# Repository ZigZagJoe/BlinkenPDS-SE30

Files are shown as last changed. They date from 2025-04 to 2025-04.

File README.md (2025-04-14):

68030 PDS Interposer / "BlinkenPDS" diagnostic board for SE/30/IIsi.

Top connector is a passthrough for card under test, side connector is for logic analyzer pins or a second card.
NOT intended for use in a case, though it will fit (poorly). 

BlinkenPDS (c) by zigzagjoe 2024

BlinkenPDS is licensed under a
Creative Commons Attribution-NonCommercial 4.0 International License.

You should have received a copy of the license along with this
work. If not, see <https://creativecommons.org/licenses/by-nc/4.0/>.

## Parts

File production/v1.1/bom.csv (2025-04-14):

Designator | Footprint | Quantity | Value | LCSC Part #
C1, C10, C11, C12, C13, C14, C15, C16, C17, C2, C23, C3, C4, C5, C6, C7, C8, C9 | 0805 | 18 | 10uF | C15850
C18, C19, C20, C21, C22 | CP_EIA-3528-15_AVX-H | 5 | 100uf | C16133
CN1 | 650949-5 RA MALE | 1 | PDS_LB_MALE
CN2 | 650874-4 RA FEMALE | 1 | PDS_PT_FEMALE RA
CN3 | 535098-5 ST FEMALE | 1 | PDS_PT_FEMALE ST
D1, D10, D11, D12, D13, D14, D15, D16, D17, D18, D19, D2, D20, D21, D22, D23, D24, D25, D26, D27, D28, D29, D3, D30, D31, D32, D4, D5, D6, D7, D8, D9 | 0603 | 32 | A | C2986059
D100, D101, D102, D65, D66, D68, D69, D70, D71, D72, D73, D74, D75, D76, D77, D78, D79, D80, D81, D82, D83, D84, D85, D86, D87, D88, D89, D90, D91, D92, D93, D94, D95, D96, D97, D98, D99 | 0603 | 37 | C | C72038
D103, D104, D105, D106 | 0603 | 4 | P | C2986058
D33, D34, D35, D36, D37, D38, D39, D40, D41, D42, D43, D44, D45, D46, D47, D48, D49, D50, D51, D52, D53, D54, D55, D56, D57, D58, D59, D60, D61, D62, D63, D64 | 0603 | 32 | D | C2286
R1, R10, R11, R12, R13, R14, R15, R16, R17, R18, R19, R2, R20, R21, R22, R23, R24, R25, R26, R27, R28, R29, R3, R30, R31, R32, R4, R5, R6, R7, R8, R9 | 0402 | 32 | 3.3K | C25890
R100, R101, R102, R33, R66, R67, R69, R70, R71, R72, R73, R74, R75, R76, R77, R78, R79, R80, R81, R82, R83, R84, R85, R86, R87, R88, R89, R90, R91, R92, R93, R94, R95, R96, R97, R98, R99 | 0402 | 37 | 510 | C25123
R103, R104 | 0402 | 2 | 680 | C25130
R105, R106 | 0402 | 2 | 2.4K | C25882
R34, R35, R36, R37, R38, R39, R40, R41, R42, R43, R44, R45, R46, R47, R48, R49, R50, R51, R52, R53, R54, R55, R56, R57, R58, R59, R60, R61, R62, R63, R64, R65 | 0402 | 32 | 1K | C25104
U1, U10, U11, U12, U13, U14, U15, U16, U17, U2, U3, U4, U5, U6, U7, U8, U9 | SOIC-14_3.9x8.7mm_P1.27mm | 17 | 74HC14D | C5605

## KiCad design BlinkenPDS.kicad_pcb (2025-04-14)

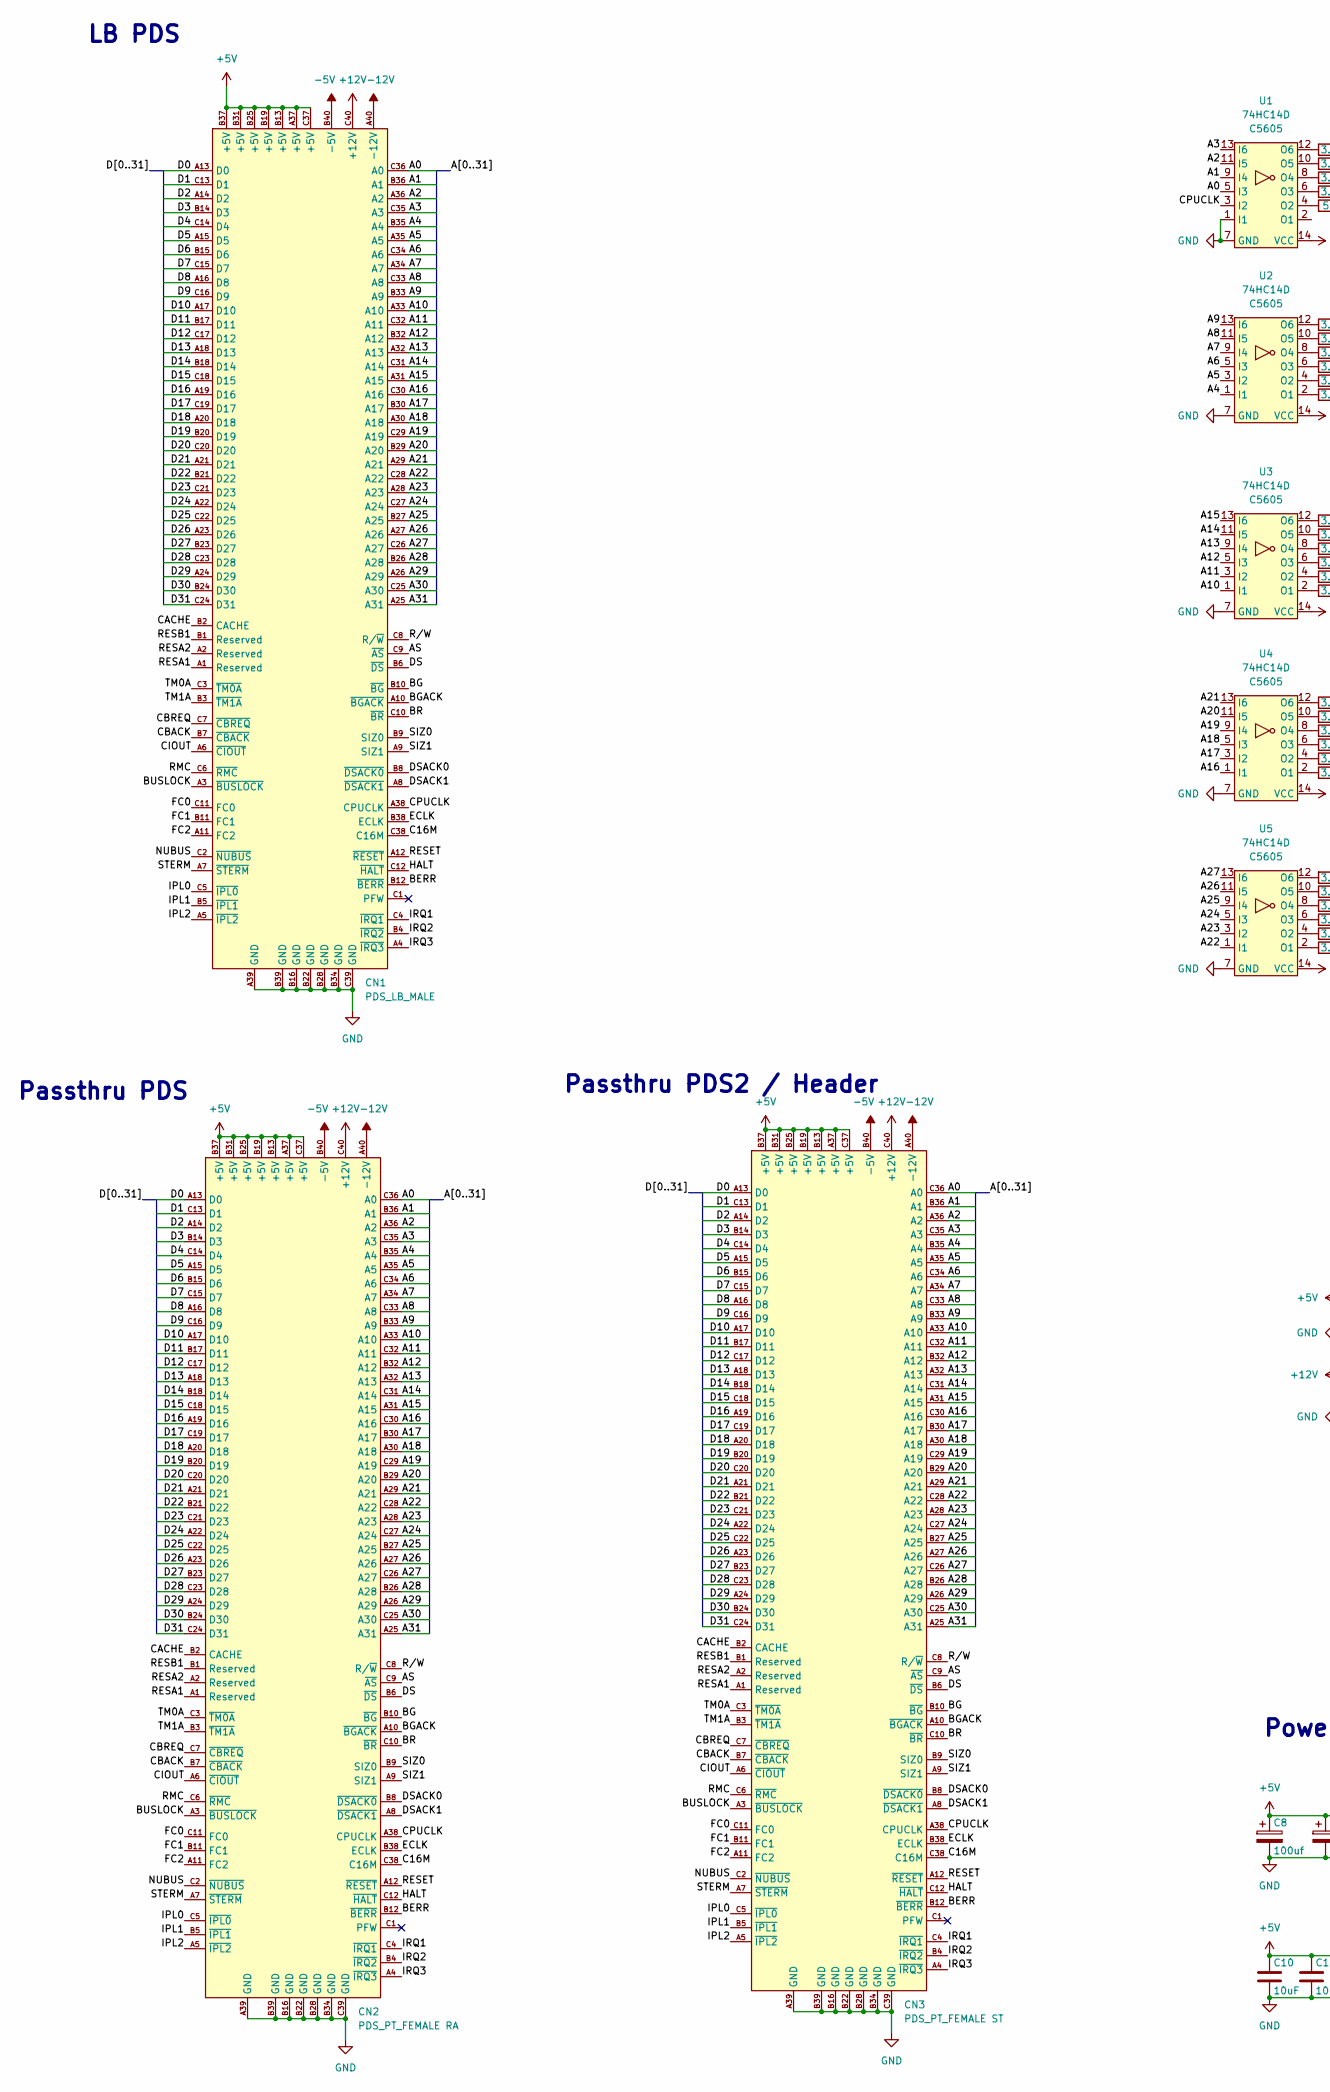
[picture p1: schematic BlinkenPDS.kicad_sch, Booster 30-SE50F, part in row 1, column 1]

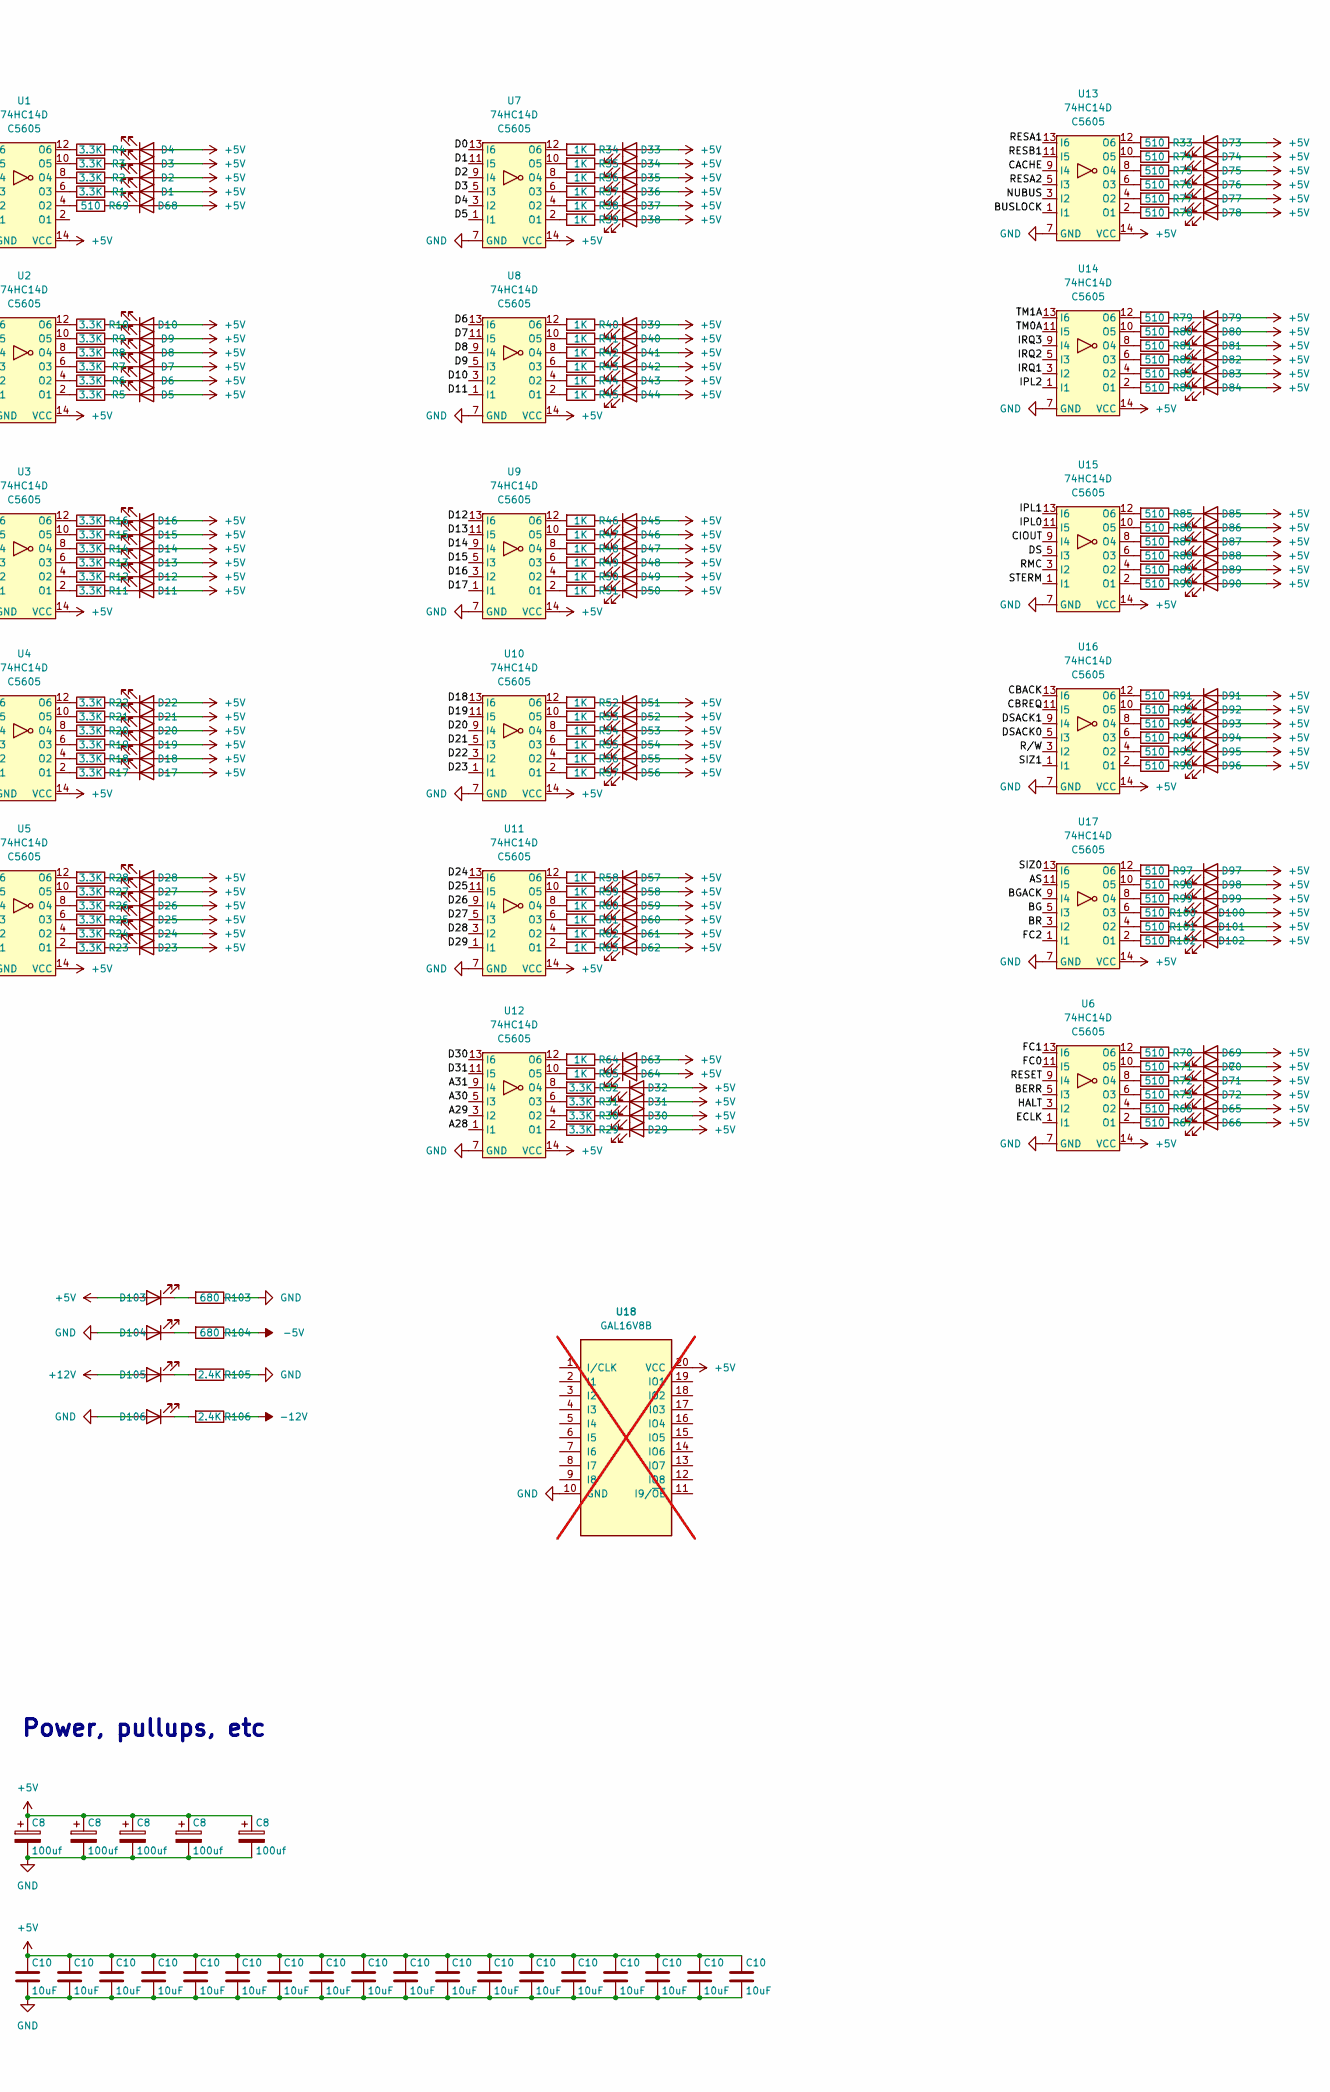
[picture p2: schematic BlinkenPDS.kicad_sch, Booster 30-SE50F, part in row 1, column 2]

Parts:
C8: 100uf; CP_EIA-3528-15_AVX-H; LCSC C16133
C10: 10uF; C_0805_2012Metric; PartNumber CL21A106KPFNNNG; LCSC C15850
CN1: PDS_LB_MALE; 650949-5 RA MALE
CN2: PDS_PT_FEMALE RA; 650874-4 RA FEMALE
CN3: PDS_PT_FEMALE ST; 535098-5 ST FEMALE
D1, D2, D3, D4, D5, D6, D7, D8, D9, D10, D11, D12, D13, D14, D15, D16, D17, D18, D19, D20, D21, D22, D23, D24, D25, D26, D27, D28, D29, D30, D31, D32: A; LED_0603_1608Metric_Label; PartNumber GRN; LCSC C2986059
D33, D34, D35, D36, D37, D38, D39, D40, D41, D42, D43, D44, D45, D46, D47, D48, D49, D50, D51, D52, D53, D54, D55, D56, D57, D58, D59, D60, D61, D62, D63, D64: D; LED_0603_1608Metric_Label; PartNumber Red; LCSC C2286
D65, D66, D68, D69, D70, D71, D72, D73, D74, D75, D76, D77, D78, D79, D80, D81, D82, D83, D84, D85, D86, D87, D88, D89, D90, D91, D92, D93, D94, D95, D96, D97, D98, D99, D100, D101, D102: C; LED_0603_1608Metric_Label; PartNumber YLW; LCSC C72038
D103, D104, D105, D106: P; LED_0603_1608Metric_Label; PartNumber Blue; LCSC C2986058
R1, R2, R3, R4, R5, R6, R7, R8, R9, R10, R11, R12, R13, R14, R15, R16, R17, R18, R19, R20, R21, R22, R23, R24, R25, R26, R27, R28, R29, R30, R31, R32: 3.3K; R_0402_1005Metric_NoLabel; LCSC C25890
R33, R66, R67, R69, R70, R71, R72, R73, R74, R75, R76, R77, R78, R79, R80, R81, R82, R83, R84, R85, R86, R87, R88, R89, R90, R91, R92, R93, R94, R95, R96, R97, R98, R99, R100, R101, R102: 510; R_0402_1005Metric_NoLabel; LCSC C25123
R34, R35, R36, R37, R38, R39, R40, R41, R42, R43, R44, R45, R46, R47, R48, R49, R50, R51, R52, R53, R54, R55, R56, R57, R58, R59, R60, R61, R62, R63, R64, R65: 1K; R_0402_1005Metric_NoLabel; LCSC C25104
R103, R104: 680; R_0402_1005Metric_NoLabel; LCSC C25130
R105, R106: 2.4K; R_0402_1005Metric_NoLabel; LCSC C25882
U1, U2, U3, U4, U5, U6, U7, U8, U9, U10, U11, U12, U13, U14, U15, U16, U17: 74HC14D; SOIC-14_3.9x8.7mm_P1.27mm; LCSC C5605
U18: GAL16V8B; DIP-20_W7.62mm_Socket_LongPads; not fitted

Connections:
+5V: C8.1, C10.1, CN1.A37 (+5V), CN1.B13 (+5V), CN1.B19 (+5V), CN1.B25 (+5V), CN1.B31 (+5V), CN1.B37 (+5V), CN1.C37 (+5V), CN2.A37 (+5V), CN2.B13 (+5V), CN2.B19 (+5V), CN2.B25 (+5V), CN2.B31 (+5V), CN2.B37 (+5V), CN2.C37 (+5V), CN3.A37 (+5V), CN3.B13 (+5V), CN3.B19 (+5V), CN3.B25 (+5V), CN3.B31 (+5V), CN3.B37 (+5V), CN3.C37 (+5V), D1.2 (A), D2.2 (A), D3.2 (A), D4.2 (A), D5.2 (A), D6.2 (A), D7.2 (A), D8.2 (A), D9.2 (A), D10.2 (A), D11.2 (A), D12.2 (A), D13.2 (A), D14.2 (A), D15.2 (A), D16.2 (A), D17.2 (A), D18.2 (A), D19.2 (A), D20.2 (A), D21.2 (A), D22.2 (A), D23.2 (A), D24.2 (A), D25.2 (A), D26.2 (A), D27.2 (A), D28.2 (A), D29.2 (A), D30.2 (A), D31.2 (A), D32.2 (A), D33.2 (A), D34.2 (A), D35.2 (A), D36.2 (A), D37.2 (A), D38.2 (A), D39.2 (A), D40.2 (A), D41.2 (A), D42.2 (A), D43.2 (A), D44.2 (A), D45.2 (A), D46.2 (A), D47.2 (A), D48.2 (A), D49.2 (A), D50.2 (A), D51.2 (A), D52.2 (A), D53.2 (A), D54.2 (A), D55.2 (A), D56.2 (A), D57.2 (A), D58.2 (A), D59.2 (A), D60.2 (A), D61.2 (A), D62.2 (A), D63.2 (A), D64.2 (A), D65.2 (A), D66.2 (A), D68.2 (A), D69.2 (A), D70.2 (A), D71.2 (A), D72.2 (A), D73.2 (A), D74.2 (A), D75.2 (A), D76.2 (A), D77.2 (A), D78.2 (A), D79.2 (A), D80.2 (A), D81.2 (A), D82.2 (A), D83.2 (A), D84.2 (A), D85.2 (A), D86.2 (A), D87.2 (A), D88.2 (A), D89.2 (A), D90.2 (A), D91.2 (A), D92.2 (A), D93.2 (A), D94.2 (A), D95.2 (A), D96.2 (A), D97.2 (A), D98.2 (A), D99.2 (A), D100.2 (A), D101.2 (A), D102.2 (A), D103.2 (A), U1.14 (VCC), U2.14 (VCC), U3.14 (VCC), U4.14 (VCC), U5.14 (VCC), U6.14 (VCC), U7.14 (VCC), U8.14 (VCC), U9.14 (VCC), U10.14 (VCC), U11.14 (VCC), U12.14 (VCC), U13.14 (VCC), U14.14 (VCC), U15.14 (VCC), U16.14 (VCC), U17.14 (VCC), U18.20 (VCC); also elsewhere on the board
+12V: CN1.C40 (+12V), CN2.C40 (+12V), CN3.C40 (+12V), D105.2 (A)
-5V: CN1.B40 (-5V), CN2.B40 (-5V), CN3.B40 (-5V), R104.1
-12V: CN1.A40 (-12V), CN2.A40 (-12V), CN3.A40 (-12V), R106.1
/A0: CN1.C36 (A0), CN2.C36 (A0), CN3.C36 (A0), U1.5 (I3)
/A1: CN1.B36 (A1), CN2.B36 (A1), CN3.B36 (A1), U1.9 (I4)
/A2: CN1.A36 (A2), CN2.A36 (A2), CN3.A36 (A2), U1.11 (I5)
/A3: CN1.C35 (A3), CN2.C35 (A3), CN3.C35 (A3), U1.13 (I6)
/A4: CN1.B35 (A4), CN2.B35 (A4), CN3.B35 (A4), U2.1 (I1)
/A5: CN1.A35 (A5), CN2.A35 (A5), CN3.A35 (A5), U2.3 (I2)
/A6: CN1.C34 (A6), CN2.C34 (A6), CN3.C34 (A6), U2.5 (I3)
/A7: CN1.A34 (A7), CN2.A34 (A7), CN3.A34 (A7), U2.9 (I4)
/A8: CN1.C33 (A8), CN2.C33 (A8), CN3.C33 (A8), U2.11 (I5)
/A9: CN1.B33 (A9), CN2.B33 (A9), CN3.B33 (A9), U2.13 (I6)
/A10: CN1.A33 (A10), CN2.A33 (A10), CN3.A33 (A10), U3.1 (I1)
/A11: CN1.C32 (A11), CN2.C32 (A11), CN3.C32 (A11), U3.3 (I2)
/A12: CN1.B32 (A12), CN2.B32 (A12), CN3.B32 (A12), U3.5 (I3)
/A13: CN1.A32 (A13), CN2.A32 (A13), CN3.A32 (A13), U3.9 (I4)
/A14: CN1.C31 (A14), CN2.C31 (A14), CN3.C31 (A14), U3.11 (I5)
/A15: CN1.A31 (A15), CN2.A31 (A15), CN3.A31 (A15), U3.13 (I6)
/A16: CN1.C30 (A16), CN2.C30 (A16), CN3.C30 (A16), U4.1 (I1)
/A17: CN1.B30 (A17), CN2.B30 (A17), CN3.B30 (A17), U4.3 (I2)
/A18: CN1.A30 (A18), CN2.A30 (A18), CN3.A30 (A18), U4.5 (I3)
/A19: CN1.C29 (A19), CN2.C29 (A19), CN3.C29 (A19), U4.9 (I4)
/A20: CN1.B29 (A20), CN2.B29 (A20), CN3.B29 (A20), U4.11 (I5)
/A21: CN1.A29 (A21), CN2.A29 (A21), CN3.A29 (A21), U4.13 (I6)
/A22: CN1.C28 (A22), CN2.C28 (A22), CN3.C28 (A22), U5.1 (I1)
/A23: CN1.A28 (A23), CN2.A28 (A23), CN3.A28 (A23), U5.3 (I2)
/A24: CN1.C27 (A24), CN2.C27 (A24), CN3.C27 (A24), U5.5 (I3)
/A25: CN1.B27 (A25), CN2.B27 (A25), CN3.B27 (A25), U5.9 (I4)
/A26: CN1.A27 (A26), CN2.A27 (A26), CN3.A27 (A26), U5.11 (I5)
/A27: CN1.C26 (A27), CN2.C26 (A27), CN3.C26 (A27), U5.13 (I6)
/A28: CN1.B26 (A28), CN2.B26 (A28), CN3.B26 (A28), U12.1 (I1)
/A29: CN1.A26 (A29), CN2.A26 (A29), CN3.A26 (A29), U12.3 (I2)
/A30: CN1.C25 (A30), CN2.C25 (A30), CN3.C25 (A30), U12.5 (I3)
/A31: CN1.A25 (A31), CN2.A25 (A31), CN3.A25 (A31), U12.9 (I4)
/AS: CN1.C9 (~AS), CN2.C9 (~AS), CN3.C9 (~AS), U17.11 (I5)
/BERR: CN1.B12 (~BERR), CN2.B12 (~BERR), CN3.B12 (~BERR), U6.5 (I3)
/BG: CN1.B10 (~BG), CN2.B10 (~BG), CN3.B10 (~BG), U17.5 (I3)
/BGACK: CN1.A10 (~BGACK), CN2.A10 (~BGACK), CN3.A10 (~BGACK), U17.9 (I4)
/BR: CN1.C10 (~BR), CN2.C10 (~BR), CN3.C10 (~BR), U17.3 (I2)
/BUSLOCK: CN1.A3 (~BUSLOCK), CN2.A3 (~BUSLOCK), CN3.A3 (~BUSLOCK), U13.1 (I1)
/C16M: CN1.C38 (C16M), CN2.C38 (C16M), CN3.C38 (C16M)
/CACHE: CN1.B2 (CACHE), CN2.B2 (CACHE), CN3.B2 (CACHE), U13.9 (I4)
/CBACK: CN1.B7 (~CBACK), CN2.B7 (~CBACK), CN3.B7 (~CBACK), U16.13 (I6)
/CBREQ: CN1.C7 (~CBREQ), CN2.C7 (~CBREQ), CN3.C7 (~CBREQ), U16.11 (I5)
/CIOUT: CN1.A6 (~CIOUT), CN2.A6 (~CIOUT), CN3.A6 (~CIOUT), U15.9 (I4)
/CPUCLK: CN1.A38 (CPUCLK), CN2.A38 (CPUCLK), CN3.A38 (CPUCLK), U1.3 (I2)
/D0: CN1.A13 (D0), CN2.A13 (D0), CN3.A13 (D0), U7.13 (I6)
/D1: CN1.C13 (D1), CN2.C13 (D1), CN3.C13 (D1), U7.11 (I5)
/D2: CN1.A14 (D2), CN2.A14 (D2), CN3.A14 (D2), U7.9 (I4)
/D3: CN1.B14 (D3), CN2.B14 (D3), CN3.B14 (D3), U7.5 (I3)
/D4: CN1.C14 (D4), CN2.C14 (D4), CN3.C14 (D4), U7.3 (I2)
/D5: CN1.A15 (D5), CN2.A15 (D5), CN3.A15 (D5), U7.1 (I1)
/D6: CN1.B15 (D6), CN2.B15 (D6), CN3.B15 (D6), U8.13 (I6)
/D7: CN1.C15 (D7), CN2.C15 (D7), CN3.C15 (D7), U8.11 (I5)
/D8: CN1.A16 (D8), CN2.A16 (D8), CN3.A16 (D8), U8.9 (I4)
/D9: CN1.C16 (D9), CN2.C16 (D9), CN3.C16 (D9), U8.5 (I3)
/D10: CN1.A17 (D10), CN2.A17 (D10), CN3.A17 (D10), U8.3 (I2)
/D11: CN1.B17 (D11), CN2.B17 (D11), CN3.B17 (D11), U8.1 (I1)
/D12: CN1.C17 (D12), CN2.C17 (D12), CN3.C17 (D12), U9.13 (I6)
/D13: CN1.A18 (D13), CN2.A18 (D13), CN3.A18 (D13), U9.11 (I5)
/D14: CN1.B18 (D14), CN2.B18 (D14), CN3.B18 (D14), U9.9 (I4)
/D15: CN1.C18 (D15), CN2.C18 (D15), CN3.C18 (D15), U9.5 (I3)
/D16: CN1.A19 (D16), CN2.A19 (D16), CN3.A19 (D16), U9.3 (I2)
/D17: CN1.C19 (D17), CN2.C19 (D17), CN3.C19 (D17), U9.1 (I1)
/D18: CN1.A20 (D18), CN2.A20 (D18), CN3.A20 (D18), U10.13 (I6)
/D19: CN1.B20 (D19), CN2.B20 (D19), CN3.B20 (D19), U10.11 (I5)
/D20: CN1.C20 (D20), CN2.C20 (D20), CN3.C20 (D20), U10.9 (I4)
/D21: CN1.A21 (D21), CN2.A21 (D21), CN3.A21 (D21), U10.5 (I3)
/D22: CN1.B21 (D22), CN2.B21 (D22), CN3.B21 (D22), U10.3 (I2)
/D23: CN1.C21 (D23), CN2.C21 (D23), CN3.C21 (D23), U10.1 (I1)
/D24: CN1.A22 (D24), CN2.A22 (D24), CN3.A22 (D24), U11.13 (I6)
/D25: CN1.C22 (D25), CN2.C22 (D25), CN3.C22 (D25), U11.11 (I5)
/D26: CN1.A23 (D26), CN2.A23 (D26), CN3.A23 (D26), U11.9 (I4)
/D27: CN1.B23 (D27), CN2.B23 (D27), CN3.B23 (D27), U11.5 (I3)
/D28: CN1.C23 (D28), CN2.C23 (D28), CN3.C23 (D28), U11.3 (I2)
/D29: CN1.A24 (D29), CN2.A24 (D29), CN3.A24 (D29), U11.1 (I1)
/D30: CN1.B24 (D30), CN2.B24 (D30), CN3.B24 (D30), U12.13 (I6)
/D31: CN1.C24 (D31), CN2.C24 (D31), CN3.C24 (D31), U12.11 (I5)
/DS: CN1.B6 (~DS), CN2.B6 (~DS), CN3.B6 (~DS), U15.5 (I3)
/DSACK0: CN1.B8 (~DSACK0), CN2.B8 (~DSACK0), CN3.B8 (~DSACK0), U16.5 (I3)
/DSACK1: CN1.A8 (~DSACK1), CN2.A8 (~DSACK1), CN3.A8 (~DSACK1), U16.9 (I4)
/ECLK: CN1.B38 (ECLK), CN2.B38 (ECLK), CN3.B38 (ECLK), U6.1 (I1)
/FC0: CN1.C11 (FC0), CN2.C11 (FC0), CN3.C11 (FC0), U6.11 (I5)
/FC1: CN1.B11 (FC1), CN2.B11 (FC1), CN3.B11 (FC1), U6.13 (I6)
/FC2: CN1.A11 (FC2), CN2.A11 (FC2), CN3.A11 (FC2), U17.1 (I1)
/HALT: CN1.C12 (~HALT), CN2.C12 (~HALT), CN3.C12 (~HALT), U6.3 (I2)
/IPL0: CN1.C5 (~IPL0), CN2.C5 (~IPL0), CN3.C5 (~IPL0), U15.11 (I5)
/IPL1: CN1.B5 (~IPL1), CN2.B5 (~IPL1), CN3.B5 (~IPL1), U15.13 (I6)
/IPL2: CN1.A5 (~IPL2), CN2.A5 (~IPL2), CN3.A5 (~IPL2), U14.1 (I1)
/IRQ1: CN1.C4 (~IRQ1), CN2.C4 (~IRQ1), CN3.C4 (~IRQ1), U14.3 (I2)
/IRQ2: CN1.B4 (~IRQ2), CN2.B4 (~IRQ2), CN3.B4 (~IRQ2), U14.5 (I3)
/IRQ3: CN1.A4 (~IRQ3), CN2.A4 (~IRQ3), CN3.A4 (~IRQ3), U14.9 (I4)
/NUBUS: CN1.C2 (~NUBUS), CN2.C2 (~NUBUS), CN3.C2 (~NUBUS), U13.3 (I2)
/RESA1: CN1.A1 (Reserved), CN2.A1 (Reserved), CN3.A1 (Reserved), U13.13 (I6)
/RESA2: CN1.A2 (Reserved), CN2.A2 (Reserved), CN3.A2 (Reserved), U13.5 (I3)
/RESB1: CN1.B1 (Reserved), CN2.B1 (Reserved), CN3.B1 (Reserved), U13.11 (I5)
/RESET: CN1.A12 (~RESET), CN2.A12 (~RESET), CN3.A12 (~RESET), U6.9 (I4)
/RMC: CN1.C6 (~RMC), CN2.C6 (~RMC), CN3.C6 (~RMC), U15.3 (I2)
/R/W: CN1.C8 (R/~W), CN2.C8 (R/~W), CN3.C8 (R/~W), U16.3 (I2)
/SIZ0: CN1.B9 (SIZ0), CN2.B9 (SIZ0), CN3.B9 (SIZ0), U17.13 (I6)
/SIZ1: CN1.A9 (SIZ1), CN2.A9 (SIZ1), CN3.A9 (SIZ1), U16.1 (I1)
/STERM: CN1.A7 (~STERM), CN2.A7 (~STERM), CN3.A7 (~STERM), U15.1 (I1)
/TM0A: CN1.C3 (~TM0A), CN2.C3 (~TM0A), CN3.C3 (~TM0A), U14.11 (I5)
/TM1A: CN1.B3 (~TM1A), CN2.B3 (~TM1A), CN3.B3 (~TM1A), U14.13 (I6)
GND: C8.2, C10.2, CN1.A39 (GND), CN1.B16 (GND), CN1.B22 (GND), CN1.B28 (GND), CN1.B34 (GND), CN1.B39 (GND), CN1.C39 (GND), CN2.A39 (GND), CN2.B16 (GND), CN2.B22 (GND), CN2.B28 (GND), CN2.B34 (GND), CN2.B39 (GND), CN2.C39 (GND), CN3.A39 (GND), CN3.B16 (GND), CN3.B22 (GND), CN3.B28 (GND), CN3.B34 (GND), CN3.B39 (GND), CN3.C39 (GND), D104.2 (A), D106.2 (A), R103.1, R105.1, U1.1 (I1), U1.7 (GND), U2.7 (GND), U3.7 (GND), U4.7 (GND), U5.7 (GND), U6.7 (GND), U7.7 (GND), U8.7 (GND), U9.7 (GND), U10.7 (GND), U11.7 (GND), U12.7 (GND), U13.7 (GND), U14.7 (GND), U15.7 (GND), U16.7 (GND), U17.7 (GND), U18.10 (GND); also elsewhere on the board
unnamed: D1.1 (K), R1.1
unnamed: D2.1 (K), R2.1
unnamed: D3.1 (K), R3.1
unnamed: D4.1 (K), R4.1
unnamed: D5.1 (K), R5.1
unnamed: D6.1 (K), R6.1
unnamed: D7.1 (K), R7.1
unnamed: D8.1 (K), R8.1
unnamed: D9.1 (K), R9.1
unnamed: D10.1 (K), R10.1
unnamed: D11.1 (K), R11.1
unnamed: D12.1 (K), R12.1
unnamed: D13.1 (K), R13.1
unnamed: D14.1 (K), R14.1
unnamed: D15.1 (K), R15.1
unnamed: D16.1 (K), R16.1
unnamed: D17.1 (K), R17.1
unnamed: D18.1 (K), R18.1
unnamed: D19.1 (K), R19.1
unnamed: D20.1 (K), R20.1
unnamed: D21.1 (K), R21.1
unnamed: D22.1 (K), R22.1
unnamed: D23.1 (K), R23.1
unnamed: D24.1 (K), R24.1
unnamed: D25.1 (K), R25.1
unnamed: D26.1 (K), R26.1
unnamed: D27.1 (K), R27.1
unnamed: D28.1 (K), R28.1
unnamed: D29.1 (K), R29.1
unnamed: D30.1 (K), R30.1
unnamed: D31.1 (K), R31.1
unnamed: D32.1 (K), R32.1
unnamed: D33.1 (K), R34.1
unnamed: D34.1 (K), R35.1
unnamed: D35.1 (K), R36.1
unnamed: D36.1 (K), R37.1
unnamed: D37.1 (K), R38.1
unnamed: D38.1 (K), R39.1
unnamed: D39.1 (K), R40.1
unnamed: D40.1 (K), R41.1
unnamed: D41.1 (K), R42.1
unnamed: D42.1 (K), R43.1
unnamed: D43.1 (K), R44.1
unnamed: D44.1 (K), R45.1
unnamed: D45.1 (K), R46.1
unnamed: D46.1 (K), R47.1
unnamed: D47.1 (K), R48.1
unnamed: D48.1 (K), R49.1
unnamed: D49.1 (K), R50.1
unnamed: D50.1 (K), R51.1
unnamed: D51.1 (K), R52.1
unnamed: D52.1 (K), R53.1
unnamed: D53.1 (K), R54.1
unnamed: D54.1 (K), R55.1
unnamed: D55.1 (K), R56.1
unnamed: D56.1 (K), R57.1
unnamed: D57.1 (K), R58.1
unnamed: D58.1 (K), R59.1
unnamed: D59.1 (K), R60.1
unnamed: D60.1 (K), R61.1
unnamed: D61.1 (K), R62.1
unnamed: D62.1 (K), R63.1
unnamed: D63.1 (K), R64.1
unnamed: D64.1 (K), R65.1
unnamed: D65.1 (K), R66.1
unnamed: D66.1 (K), R67.1
unnamed: D68.1 (K), R69.1
unnamed: D69.1 (K), R70.1
unnamed: D70.1 (K), R71.1
unnamed: D71.1 (K), R72.1
unnamed: D72.1 (K), R73.1
unnamed: D73.1 (K), R33.1
unnamed: D74.1 (K), R74.1
unnamed: D75.1 (K), R75.1
unnamed: D76.1 (K), R76.1
unnamed: D77.1 (K), R77.1
unnamed: D78.1 (K), R78.1
unnamed: D79.1 (K), R79.1
unnamed: D80.1 (K), R80.1
unnamed: D81.1 (K), R81.1
unnamed: D82.1 (K), R82.1
unnamed: D83.1 (K), R83.1
unnamed: D84.1 (K), R84.1
unnamed: D85.1 (K), R85.1
unnamed: D86.1 (K), R86.1
unnamed: D87.1 (K), R87.1
unnamed: D88.1 (K), R88.1
unnamed: D89.1 (K), R89.1
unnamed: D90.1 (K), R90.1
unnamed: D91.1 (K), R91.1
unnamed: D92.1 (K), R92.1
unnamed: D93.1 (K), R93.1
unnamed: D94.1 (K), R94.1
unnamed: D95.1 (K), R95.1
unnamed: D96.1 (K), R96.1
unnamed: D97.1 (K), R97.1
unnamed: D98.1 (K), R98.1
unnamed: D99.1 (K), R99.1
unnamed: D100.1 (K), R100.1
unnamed: D101.1 (K), R101.1
unnamed: D102.1 (K), R102.1
unnamed: D103.1 (K), R103.2
unnamed: D104.1 (K), R104.2
unnamed: D105.1 (K), R105.2
unnamed: D106.1 (K), R106.2
unnamed: R69.2, U1.4 (O2)
unnamed: R1.2, U1.6 (O3)
unnamed: R2.2, U1.8 (O4)
unnamed: R3.2, U1.10 (O5)
unnamed: R4.2, U1.12 (O6)
unnamed: R5.2, U2.2 (O1)
unnamed: R6.2, U2.4 (O2)
unnamed: R7.2, U2.6 (O3)
unnamed: R8.2, U2.8 (O4)
unnamed: R9.2, U2.10 (O5)
unnamed: R10.2, U2.12 (O6)
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

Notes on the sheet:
Passthru PDS
Power, pullups, etc
LB PDS
Passthru PDS2 / Header

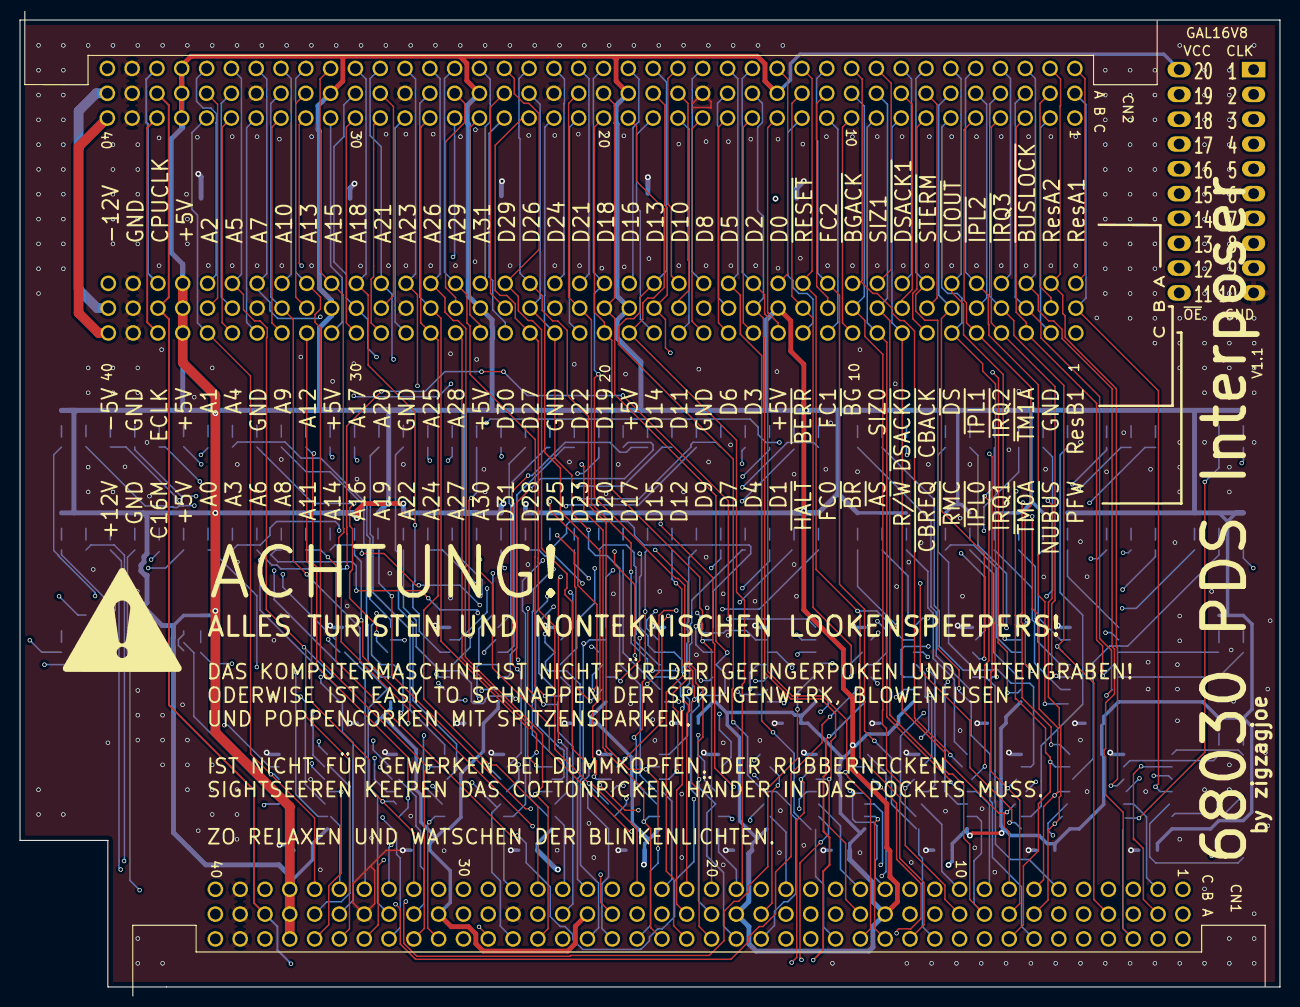
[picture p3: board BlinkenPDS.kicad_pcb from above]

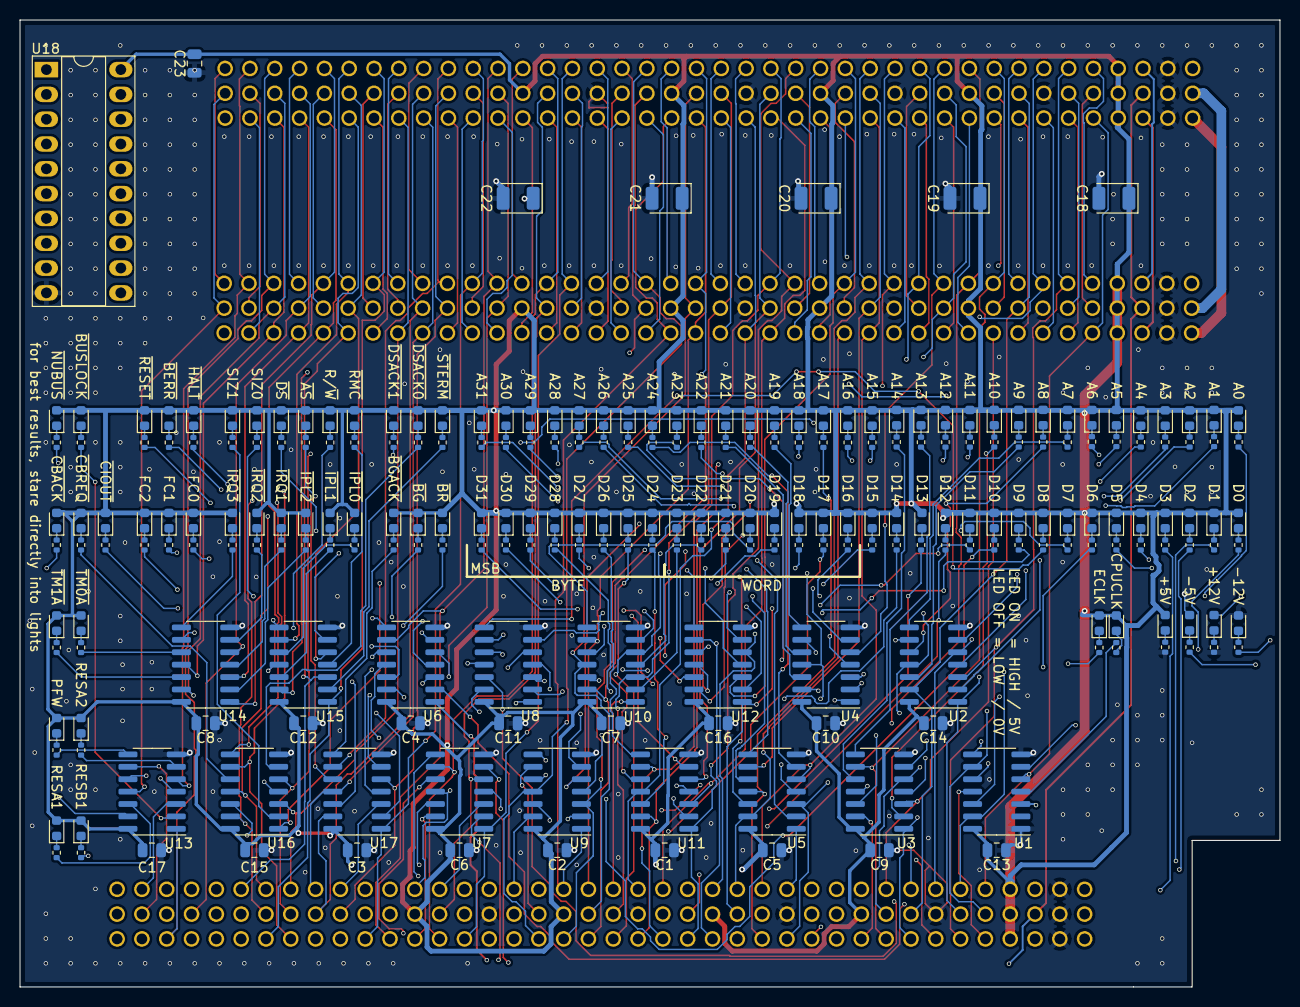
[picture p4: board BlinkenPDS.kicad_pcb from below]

Board: 4 copper layers, 129.0 x 99.0 mm, 254 parts (251 on the bottom side), 313 nets.

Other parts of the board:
C1, C2, C3, C4, C5, C6, C7, C9, C11, C12, C13, C14, C15, C16, C17, C23: 10uF; C_0805_2012Metric
C18, C19, C20, C21, C22: 100uf; CP_EIA-3528-15_AVX-H

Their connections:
+5V: C1.1, C2.1, C3.1, C4.1, C5.1, C6.1, C7.1, C9.1, C11.1, C12.1, C13.1, C14.1, C15.1, C16.1, C17.1, C18.1, C19.1, C20.1, C21.1, C22.1, C23.1; also elsewhere on the board
GND: C1.2, C2.2, C3.2, C4.2, C5.2, C6.2, C7.2, C9.2, C11.2, C12.2, C13.2, C14.2, C15.2, C16.2, C17.2, C18.2, C19.2, C20.2, C21.2, C22.2, C23.2; also elsewhere on the board
